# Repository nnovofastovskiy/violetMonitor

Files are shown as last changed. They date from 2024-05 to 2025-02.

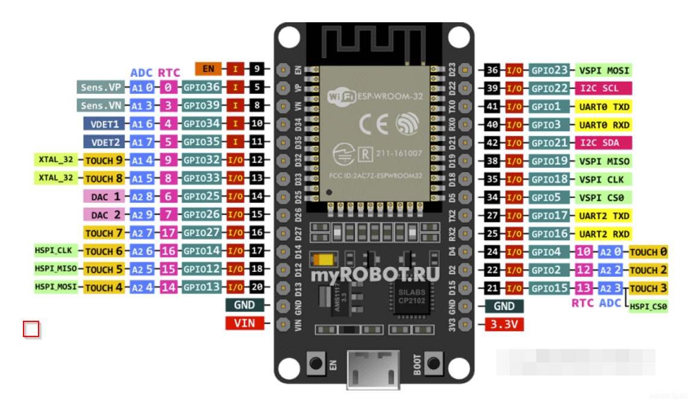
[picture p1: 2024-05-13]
datasheets/esp32_006img03.png





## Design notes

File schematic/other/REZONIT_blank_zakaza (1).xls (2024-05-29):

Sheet: Лист1
8-800-777-80-80 pcb@rezonit.ru
Отправляя заполненный бланк на email: pcb@rezonit.ru я соглашаюсь с условиями Политики обработки персональных данных, даю Согласие на обработку персональных данных (https://www.rezonit.ru/docs/politics/) | https://www.rezonit.ru/docs/politics/ | https://www.rezonit.ru/docs/politics/ | https://www.rezonit.ru/docs/politics/ | https://www.rezonit.ru/docs/politics/ | https://www.rezonit.ru/docs/politics/ | https://www.rezonit.ru/docs/politics/ | https://www.rezonit.ru/docs/politics/ | https://www.rezonit.ru/docs/politics/ | https://www.rezonit.ru/docs/politics/ | https://www.rezonit.ru/docs/politics/ | https://www.rezonit.ru/docs/politics/ | https://www.rezonit.ru/docs/politics/ | https://www.rezonit.ru/docs/politics/ | https://www.rezonit.ru/docs/politics/ | https://www.rezonit.ru/docs/politics/ | https://www.rezonit.ru/docs/politics/ | https://www.rezonit.ru/docs/politics/ | https://www.rezonit.ru/docs/politics/ | https://www.rezonit.ru/docs/politics/ | https://www.rezonit.ru/docs/politics/ | https://www.rezonit.ru/docs/politics/ | https://www.rezonit.ru/docs/politics/
https://www.rezonit.ru/docs/politics/ | https://www.rezonit.ru/docs/politics/ | https://www.rezonit.ru/docs/politics/ | https://www.rezonit.ru/docs/politics/ | https://www.rezonit.ru/docs/politics/ | https://www.rezonit.ru/docs/politics/ | https://www.rezonit.ru/docs/politics/ | https://www.rezonit.ru/docs/politics/ | https://www.rezonit.ru/docs/politics/ | https://www.rezonit.ru/docs/politics/ | https://www.rezonit.ru/docs/politics/ | https://www.rezonit.ru/docs/politics/ | https://www.rezonit.ru/docs/politics/ | https://www.rezonit.ru/docs/politics/ | https://www.rezonit.ru/docs/politics/ | https://www.rezonit.ru/docs/politics/ | https://www.rezonit.ru/docs/politics/ | https://www.rezonit.ru/docs/politics/ | https://www.rezonit.ru/docs/politics/ | https://www.rezonit.ru/docs/politics/ | https://www.rezonit.ru/docs/politics/ | https://www.rezonit.ru/docs/politics/ | https://www.rezonit.ru/docs/politics/
Даю Согласие на получение рассылки рекламно-информационных материалов (https://www.rezonit.ru/docs/soglasie-na-poluchenie-rassylki-reklamno-informatsionnykh-materialov/) | https://www.rezonit.ru/docs/soglasie-na-poluchenie-rassylki-reklamno-informatsionnykh-materialov/ | https://www.rezonit.ru/docs/soglasie-na-poluchenie-rassylki-reklamno-informatsionnykh-materialov/ | https://www.rezonit.ru/docs/soglasie-na-poluchenie-rassylki-reklamno-informatsionnykh-materialov/ | https://www.rezonit.ru/docs/soglasie-na-poluchenie-rassylki-reklamno-informatsionnykh-materialov/ | https://www.rezonit.ru/docs/soglasie-na-poluchenie-rassylki-reklamno-informatsionnykh-materialov/ | https://www.rezonit.ru/docs/soglasie-na-poluchenie-rassylki-reklamno-informatsionnykh-materialov/ | https://www.rezonit.ru/docs/soglasie-na-poluchenie-rassylki-reklamno-informatsionnykh-materialov/ | https://www.rezonit.ru/docs/soglasie-na-poluchenie-rassylki-reklamno-informatsionnykh-materialov/ | https://www.rezonit.ru/docs/soglasie-na-poluchenie-rassylki-reklamno-informatsionnykh-materialov/ | https://www.rezonit.ru/docs/soglasie-na-poluchenie-rassylki-reklamno-informatsionnykh-materialov/ | https://www.rezonit.ru/docs/soglasie-na-poluchenie-rassylki-reklamno-informatsionnykh-materialov/ | https://www.rezonit.ru/docs/soglasie-na-poluchenie-rassylki-reklamno-informatsionnykh-materialov/ | https://www.rezonit.ru/docs/soglasie-na-poluchenie-rassylki-reklamno-informatsionnykh-materialov/ | https://www.rezonit.ru/docs/soglasie-na-poluchenie-rassylki-reklamno-informatsionnykh-materialov/ | https://www.rezonit.ru/docs/soglasie-na-poluchenie-rassylki-reklamno-informatsionnykh-materialov/ | https://www.rezonit.ru/docs/soglasie-na-poluchenie-rassylki-reklamno-informatsionnykh-materialov/ | https://www.rezonit.ru/docs/soglasie-na-poluchenie-rassylki-reklamno-informatsionnykh-materialov/ | https://www.rezonit.ru/docs/soglasie-na-poluchenie-rassylki-reklamno-informatsionnykh-materialov/ | https://www.rezonit.ru/docs/soglasie-na-poluchenie-rassylki-reklamno-informatsionnykh-materialov/ | https://www.rezonit.ru/docs/soglasie-na-poluchenie-rassylki-reklamno-informatsionnykh-materialov/ | https://www.rezonit.ru/docs/soglasie-na-poluchenie-rassylki-reklamno-informatsionnykh-materialov/ | https://www.rezonit.ru/docs/soglasie-na-poluchenie-rassylki-reklamno-informatsionnykh-materialov/
https://www.rezonit.ru/docs/soglasie-na-poluchenie-rassylki-reklamno-informatsionnykh-materialov/ | https://www.rezonit.ru/docs/soglasie-na-poluchenie-rassylki-reklamno-informatsionnykh-materialov/ | https://www.rezonit.ru/docs/soglasie-na-poluchenie-rassylki-reklamno-informatsionnykh-materialov/ | https://www.rezonit.ru/docs/soglasie-na-poluchenie-rassylki-reklamno-informatsionnykh-materialov/ | https://www.rezonit.ru/docs/soglasie-na-poluchenie-rassylki-reklamno-informatsionnykh-materialov/ | https://www.rezonit.ru/docs/soglasie-na-poluchenie-rassylki-reklamno-informatsionnykh-materialov/ | https://www.rezonit.ru/docs/soglasie-na-poluchenie-rassylki-reklamno-informatsionnykh-materialov/ | https://www.rezonit.ru/docs/soglasie-na-poluchenie-rassylki-reklamno-informatsionnykh-materialov/ | https://www.rezonit.ru/docs/soglasie-na-poluchenie-rassylki-reklamno-informatsionnykh-materialov/ | https://www.rezonit.ru/docs/soglasie-na-poluchenie-rassylki-reklamno-informatsionnykh-materialov/ | https://www.rezonit.ru/docs/soglasie-na-poluchenie-rassylki-reklamno-informatsionnykh-materialov/ | https://www.rezonit.ru/docs/soglasie-na-poluchenie-rassylki-reklamno-informatsionnykh-materialov/ | https://www.rezonit.ru/docs/soglasie-na-poluchenie-rassylki-reklamno-informatsionnykh-materialov/ | https://www.rezonit.ru/docs/soglasie-na-poluchenie-rassylki-reklamno-informatsionnykh-materialov/ | https://www.rezonit.ru/docs/soglasie-na-poluchenie-rassylki-reklamno-informatsionnykh-materialov/ | https://www.rezonit.ru/docs/soglasie-na-poluchenie-rassylki-reklamno-informatsionnykh-materialov/ | https://www.rezonit.ru/docs/soglasie-na-poluchenie-rassylki-reklamno-informatsionnykh-materialov/ | https://www.rezonit.ru/docs/soglasie-na-poluchenie-rassylki-reklamno-informatsionnykh-materialov/ | https://www.rezonit.ru/docs/soglasie-na-poluchenie-rassylki-reklamno-informatsionnykh-materialov/ | https://www.rezonit.ru/docs/soglasie-na-poluchenie-rassylki-reklamno-informatsionnykh-materialov/ | https://www.rezonit.ru/docs/soglasie-na-poluchenie-rassylki-reklamno-informatsionnykh-materialov/ | https://www.rezonit.ru/docs/soglasie-na-poluchenie-rassylki-reklamno-informatsionnykh-materialov/ | https://www.rezonit.ru/docs/soglasie-na-poluchenie-rassylki-reklamno-informatsionnykh-materialov/
Наименование компании / ФИО заказчика |  |  |  |  |  |  |  | Новофастовский Никита Андреевич
Вид плательщика |  |  |  |  |  |  |  | Физическое лицо
ФИО плательщика (если различно с заказчиком)
 |  |  |  |  |  |  |  | необходимо заполнить
 |  |  |  |  |  |  |  | необходимо заполнить
Способ получения плат |  |  |  |  |  |  |  | Доставка
Способ доставки |  |  |  |  |  |  |  | Экспресс-доставка
Адрес доставки заказа, примечания по доставке |  |  |  |  |  |  |  | 117342, Россия, г Москва, р-н Коньково, ул Введенского, д 1 стр 21 Адрес проходной предприятия, доставку могу принять с понедельника по пятницу с 10:00 до 18:00, курьеру позвонить за 15 мин до прибытия.
Контактное лицо по доставке (ФИО, email, тел) |  |  |  |  |  |  |  | Новофастовский Никита Андреевич, bananchik26@gmail.com, +7(999)9796726
Контактное лицо по техническим вопросам (ФИО, email, тел) |  |  |  |  |  |  |  | Новофастовский Никита Андреевич, bananchik26@gmail.com, +7(999)9796726
Характеристика проекта |  |  |  |  |  |  |  | ! Убедитесь, что проект платы соответствует нашим технологическим возможностям. В случае несоответствия им адаптация проекта проходит без дополнительного согласования
Наименование файла платы: |  |  |  |  |  |  |  | violetMonitor |  |  |  |  |  |  | Дополнительные требования
Плата изготавливается: впервые / повторно |  |  |  |  |  |  |  | Впервые
Вариант изготовления |  |  |  |  |  |  |  | Суперсрочный
Требуется изготовить, шт |  |  |  |  |  |  |  | 1
Количество проводящих слоев |  |  |  |  |  |  |  | 2
Базовый материал (Core) |  |  |  |  |  |  |  | FR4 Tg135 типовой
Толщина материала (ОПП, ДПП)/Суммарная толщина платы ( МПП), мм |  |  |  |  |  |  |  | 1.500
Толщина фольги, мкм |  |  |  |  |  |  |  | 18
Финишное покрытие площадок |  |  |  |  |  |  |  | ПОС-63
Наличие паяльной маски |  |  |  |  |  |  |  | Маска с 2 сторон |  |  | Зеленого(типового)цвета
Наличие маркировки краской |  |  |  |  |  |  |  | С 2 сторон |  |  | белого(типового)цвета
Монтаж и изготовление трафарета |  |  |  |  |  |  |  | Требуется с закупкой комплектации
Вариант монтажного заказа |  |  |  |  |  |  |  | Срочный
Требуется смонтировать шт |  |  |  |  |  |  |  | 1
Паяльная паста |  |  |  |  |  |  |  | с содержанием свинца (стандартный)
Отмывка плат после монтажа |  |  |  |  |  |  |  | не требуется
Разделение плат после монтажа |  |  |  |  |  |  |  | не требуется
Рентген-контроль |  |  |  |  |  |  |  | не требуется
Перечень технологических слоев |  |  |  |  |  |  |  | поля заполнены типовыми значениями, при необходимости можете заполнить
 |  |  | Имя Gerber файла_Layer name (PCAD200x)_Слои в PCAD4.5(8.5)_DipTrace |  |  |  |  | Типовая сборка |  |  | Требуемая сборка |  | Сверловка, укажите цветом начальный и конечный слой
Контур платы
Маркировка элементов сверху |  |  |  |  |  |  |  |  |  |  |  |  | Сквозные металлизированные отверстия |  | Сквозные неметаллизированные отверстия
Маска верхнего слоя
Верхний слой |  |  |  |  |  |  |  | фольга 18 мкм
Внутренний
Внутренний
Внутренний
Внутренний
 |  |  |  |  |  |  |  | FR4 Tg135 типовой 1,5 мм
Внутренний
Внутренний
Внутренний
Внутренний
Внутренний
Внутренний
Внутренний
Внутренний
Нижний слой |  |  |  |  |  |  |  | фольга 18 мкм
Маска нижнего слоя
Маркировка элементов снизу
PTH
NPTH
Несквозные отверстия 1
Несквозные отверстия 2
Несквозные отверстия 3
Расширенные параметры печатной платы (сборка, мех. обработка и т.д.) |  |  |  |  |  |  |  | поля заполнены типовыми значениями, при необходимости можете изменить их
Электротестирование
Контроль волнового сопротивления (импеданс) |  |  |  |  |  |  |  | Нет
Покрытие краевых разъемов |  |  |  |  |  |  |  | Соответствует финишному покрытию
Фаска 30 грд на краевых разъемах
Механическая обработка контура |  |  |  |  |  |  |  | На усмотрение производства
Металлизированный торец платы |  |  |  |  |  |  |  | Нет
Металлизированные полуотверстия
Металлизированные пазы
Зенковка |  |  |  |  |  |  |  | Нет
Фрезерование на глубину |  |  |  |  |  |  |  | Нет
Структура МПП |  |  |  |  |  |  |  | Типовая
Для PCAD4.5;8.5;2000; Diptrace; Altium Designer переходные |  |  |  |  |  |  |  | Закрыты маской
Тентирование переходных отверстий |  |  |  |  |  |  |  | Не требуется
Для экспорта шелкографии в PCAD200x мы используем след. настройки по умолчанию |  |  |  |  |  |  |  | RefDes | On | Type | Off | Value | Off
Панелизация |  |  |  |  |  |  |  | На усмотрение производcтва |  |  |  |  |  |  | Панелизация необходима для качественного монтажа электронных компонентов. Если платы будут монтироваться в компании Резонит рекомендуем выбрать раскладку панели «На усмотрение производcтва». ! Монтаж единичных плат, не объединенных в заготовку, невозможен на нашем производстве.
Длина платы (по горизонтали), мм
Ширина платы (по вертикали), мм
Количество плат по горизонтали
Количество плат по вертикали
Зазор между платами по горизонтали
Зазор между платами по вертикали
Ширина полей по горизонтали
Ширина полей по вертикали
Маркировка плат по ГОСТ 30668-2000
Ремонт на печатных платах по ГОСТ Р 55491-2013 |  |  |  |  |  |  |  | Допускается
Нулевой дефект на панели (No X-out) |  |  |  |  |  |  |  | Нет
Описание PIN & VIA PCAD-4.5 и PCAD8.5.
Масштаб изготовления фотошаблона |  |  |  |  |  |  |  | 1:1
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

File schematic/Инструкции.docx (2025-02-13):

При включении контроллер проверяет наличие сохраненных данных wifi и url, при отсутствии данных запускается точка доступа с названием “violetMonitor”. При подключении к этой точке доступа автоматически откроется веб-страница для настройки (по адресу 192.168.4.1, таймаут для подключения к точке доступа 20 секунд; если не подключиться к точке доступа питание отключится, включить его можно кнопкой включения).

На странице настроек нужно сначала перейти на страницу «Параметры», ввести URL для получения данных, изменить если нужно частоту обновления данных и яркость светодиода и нажать «Сохранить», после этого, вернуться на главную страницу.

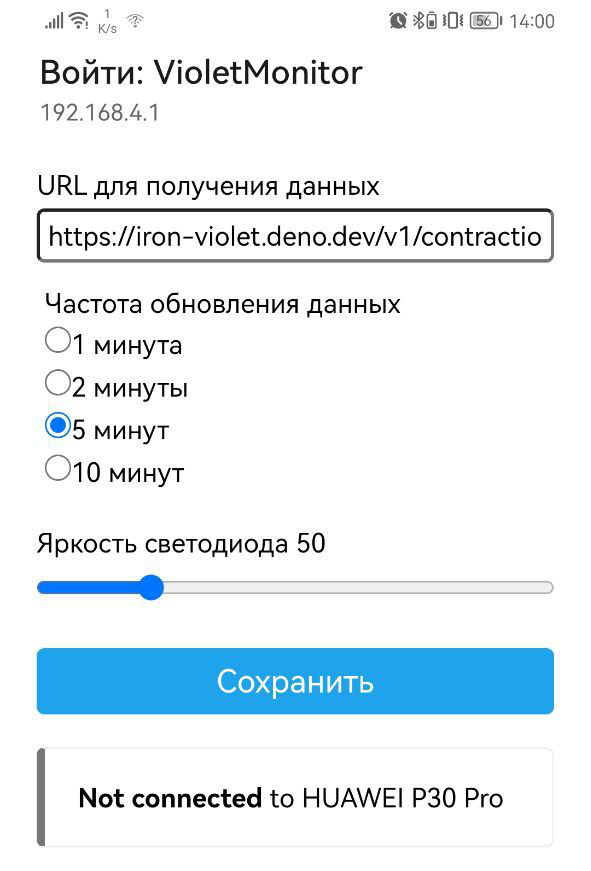
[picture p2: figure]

Далее нажать «Настроить WiFi».

На странице настройки WiFi выбрать сеть из списка, ввести пароль этой сети и нажать «Сохранить», после этого точка доступа отключится, и устройство попытается подключиться к сохраненной WiFi сети.

Если подключиться не получится, автоматически запустится точка доступа и можно будет исправить настройки.

Если подключение к wifi произошло, контроллер выполнит http запрос по сохраненному url, получит данные, распарсит их и начнет измерение уровня заряда аккумулятора (кол-во импульсов с микросхемы контроллера питания).

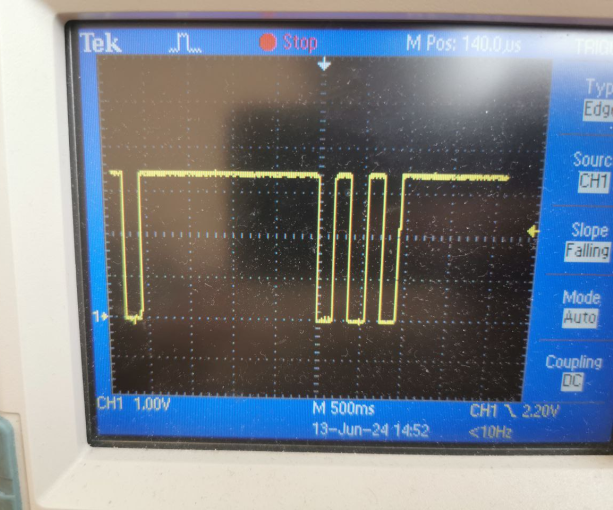
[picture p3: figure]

После измерения информация выводится на дисплей, и контроллер переходит в режим глубокого сна на заданное время.

После пробуждения алгоритм повторяется.

Устройство можно выключить/включить кнопкой вкл/выкл.

Точку доступа можно принудительно запустить соответствующей кнопкой для изменения настроек.

Во время зарядки отображается значок .

Когда аккумулятор полностью зарядится, отобразится значок .

Когда аккумулятор полностью разрядится, информация на дисплее останется в последнем состоянии, но светодиод погаснет.

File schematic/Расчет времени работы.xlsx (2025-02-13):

частота мин | ток | секунды | потребление мА/ч | емкость мАч | часов | дней
1 | 120 | 4 | 20.85 | 2000 | 95.92326139 | 3.996802558
 | 70 | 9
 | 3 | 47

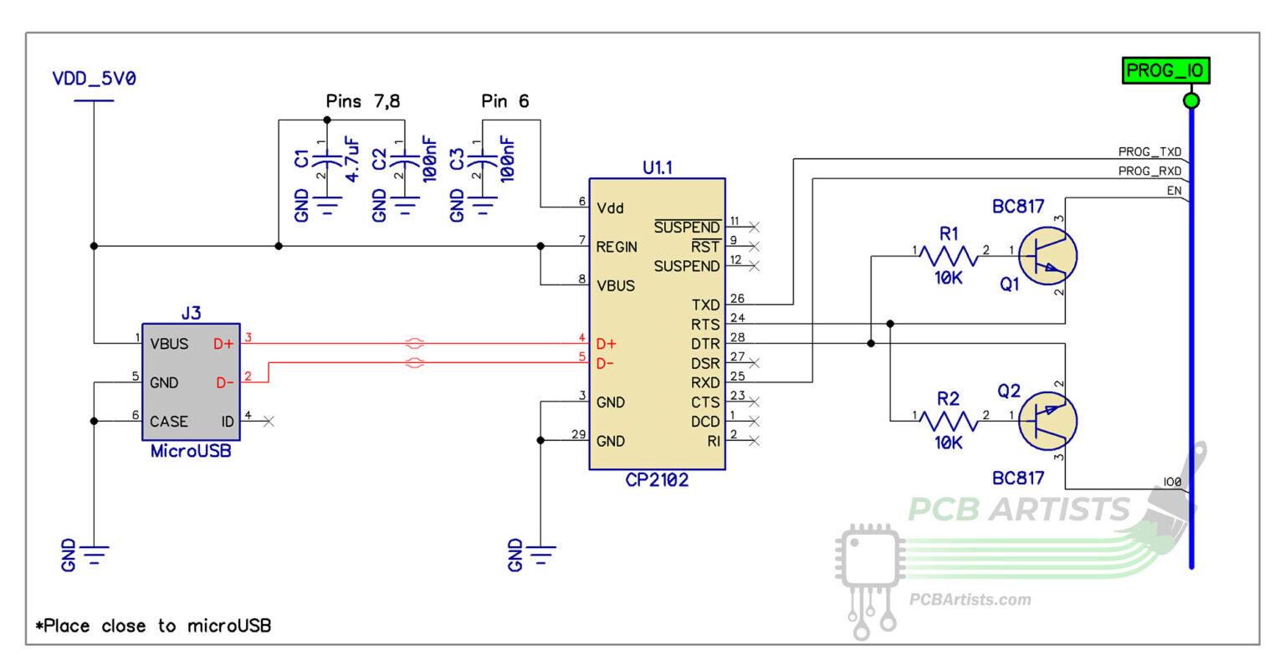
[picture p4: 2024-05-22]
datasheets/esp32-cp2102-programmer-schematic-for-espressif-esp32-esp8266-1536x802.jpg

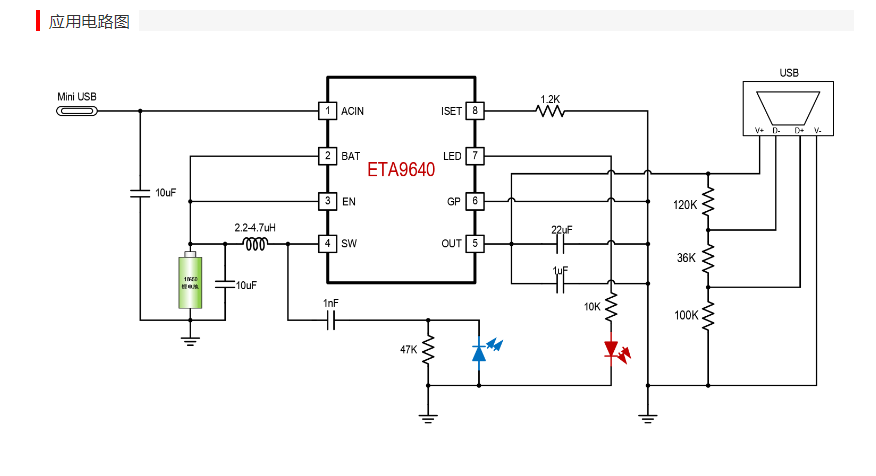
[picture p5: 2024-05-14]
datasheets/eta9640.png

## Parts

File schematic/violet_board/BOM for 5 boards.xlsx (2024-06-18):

# | RefDes | Name | Pattern | Value | Quantity | Всего нужно | На руках | Купить
1 | C1, C2, C7 | GRM21BR61A106KE19B | CAP_0805_L | 10uF | 3 | 15 | 4 | 11
2 | C3 | GRM32ER71E226KE15L | CAP_1210_L | 22uF | 1 | 5 | 8 | 0
3 | C4, C9, C10, C11 | GRM155R61C105KA12D | CAP_0402_L | 1uF | 4 | 20 | 0 | 20
4 | C5 | GRM2165C1H471JA01D | CAP_0805_L | 470pF | 1 | 5 | 8 | 0
5 | C6 | TECAP2.2/16VA10 | CAPPM320X160X185L80X120N | 2.2uF | 1 | 5 | 0 | 5
6 | C8, C12 | GRM21BR71H104K | CAP_0805_L | 0.1uF | 2 | 10 | 9 | 1
7 | IC1 | SK6805-2427 | SK68052427 |  | 1 | 5 | 8 | 0
8 | L1 | B82472G6472M000 | IND(4.7)_B82472G6472M000 | 4.7uH | 1 | 5 | 2 | 3
9 | Q1, Q2 | BSS138LT1G | SOT23-3P95_240X110L43X44N |  | 2 | 10 | 9 | 1
10 | Q3, Q4 | BC817-16,235 | SOT23-3P95_230X110L30X43N |  | 2 | 10 | 10 | 0
11 | R1 | RC0402FR-071K2L | RES_0402_L | 1.2k | 1 | 5 | 18 | 0
12 | R2, R3, R4, R8 | RC0402FR-0730KL | RES_0402_L | 30k | 4 | 20 | 15 | 5
13 | R5, R9, R10, R11, R12 | RC0805JR-0710KL | RES_0805_L | 10k | 5 | 25 | 10 | 15
14 | R6, R7 | RC0402JR-07390RL | RES_0402_L | 390R | 2 | 10 | 16 | 0
15 | U1 | ETA9640 | SOIC9P127_493X599X154L63X40T285X225M |  | 1 | 5 | 10 | 0
16 | U2 | MIC5219-3.3YM5 | SOT23-5 |  | 1 | 5 | 9 | 0
17 | U3 | ESP32-WROOM-32 | MODULE_ESP32-WROOM-32 |  | 1 | 5 | 0 | 5
18 | XP1, XP2, XP5, XP6, XP7 | DS1066-02M | DS1066-02M |  | 5 | 25 | 10 | 15
19 | XP3, XP4 | PLS_20 | PLS_20 |  | 2 | 10 | 4 | 6
20 | XP8 | PLS_6R | PLS_6R |  | 1 | 5 | 4 | 1
21 |  | DS1066-02F |  |  | 5 | 25 | 5 | 20
22 |  | LP103450-PCM |  |  | 1 | 5 | 0 | 5
23 |  | Pico-ePaper-2.9 | 9000791762 |  | 1 | 5 | 0 | 5

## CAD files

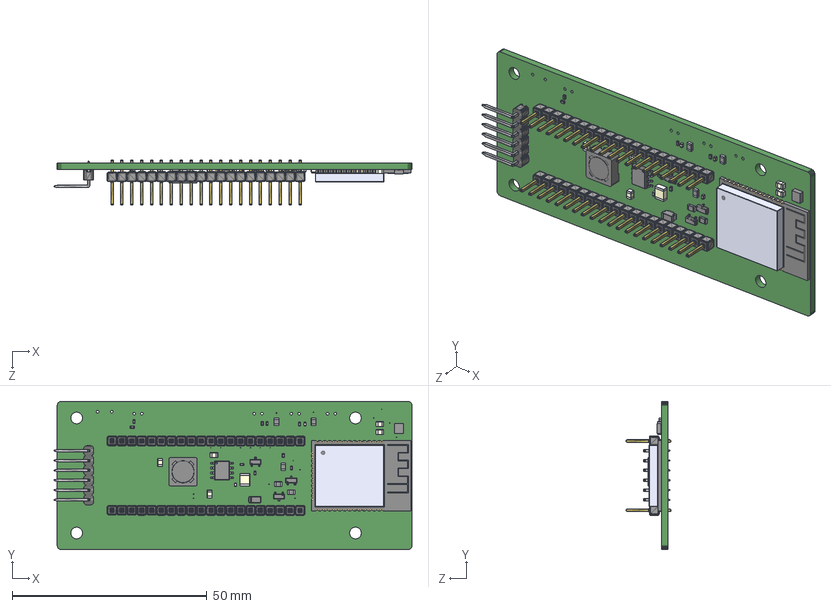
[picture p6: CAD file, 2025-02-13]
schematic/other/main.step
91.8 x 38.0 x 11.6 mm
Board___wctmp
GRM21BR61A106KE19B x 5
GRM32ER71E226KE15L
GRM155R61C105KA12D x 4
TECAP2.2/16VA10
t_mod_0 x 2
BSS138LT1G
BC817-16,235 x 2
RC0402FR-071K2L x 7
RC0805JR-0710KL x 5
ETA9640
t_mod_1
pls_20 x 2
pls_6R

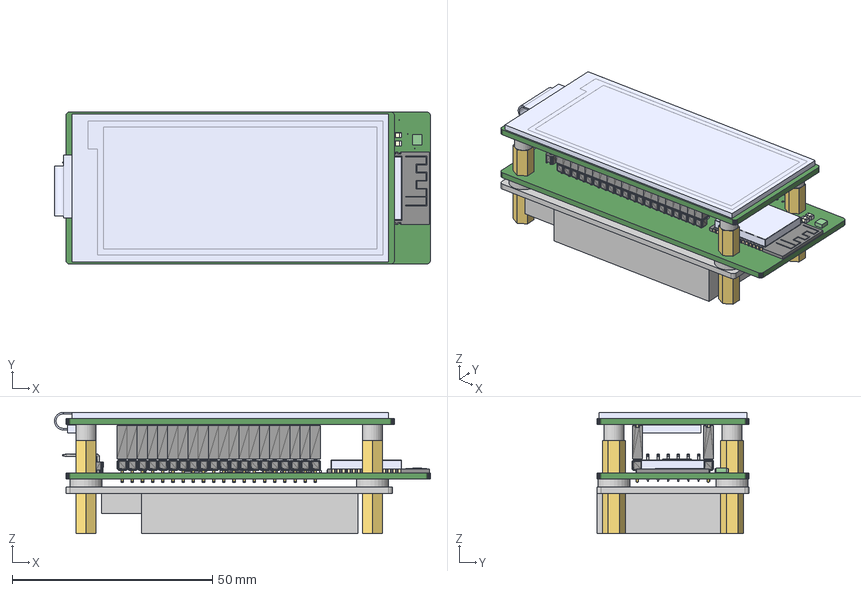
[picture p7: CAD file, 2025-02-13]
schematic/other/Assembly v9.step
93.8 x 38.0 x 30.3 mm
PCHSN-8 x 4
Board___wctmp
GRM21BR61A106KE19B x 5
GRM32ER71E226KE15L
GRM155R61C105KA12D x 4
TECAP2.2/16VA10
t_mod_0
t_mod_0 (1)
BSS138LT1G
BC817-16,235 x 2
RC0402FR-071K2L x 7
RC0805JR-0710KL x 5
ETA9640
t_mod_1
pls_20 x 2
pls_6R
Board___wctmp_1
PBS_20 x 2
LP103450 battery
Plane
PCHSN-10 v1 x 4

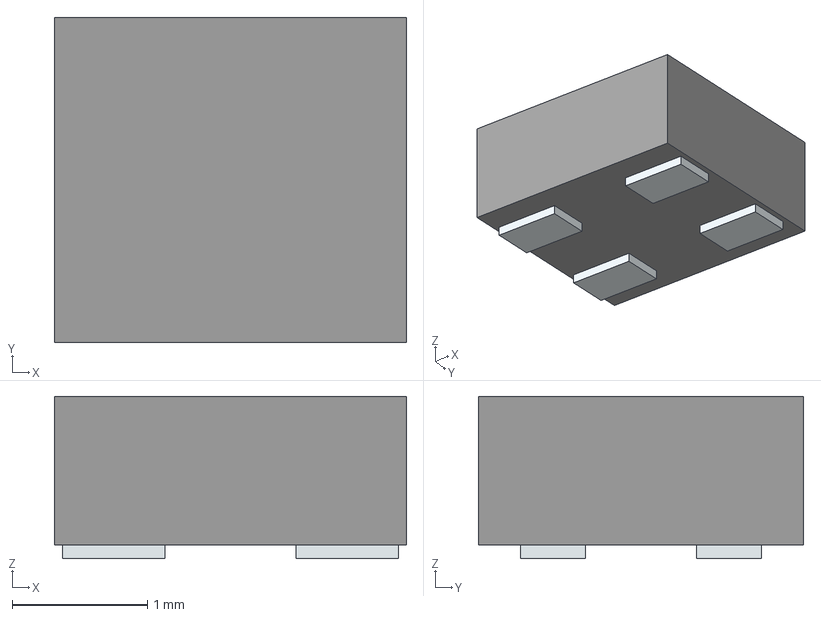
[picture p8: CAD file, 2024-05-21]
schematic/My Libraries/SK6805-2427.stp
2.60 x 2.40 x 1.20 mm
Pins

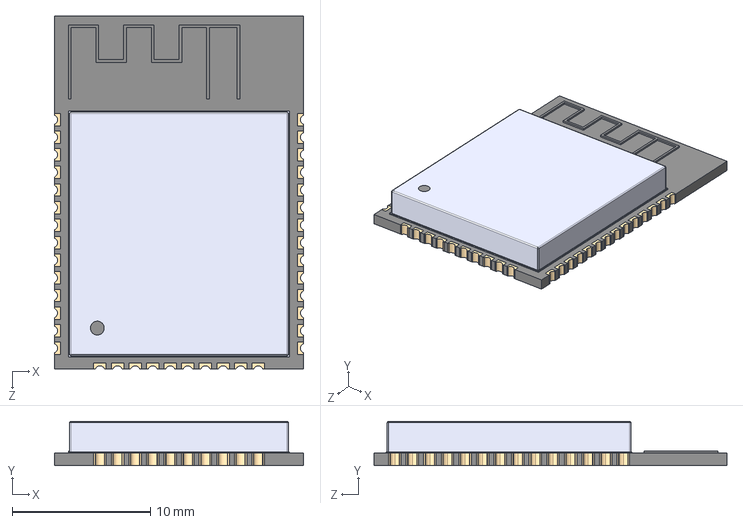
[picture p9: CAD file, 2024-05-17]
schematic/My Libraries/ESP32-WROOM-32--3DModel-STEP-1.STEP
18.0 x 3.20 x 25.5 mm

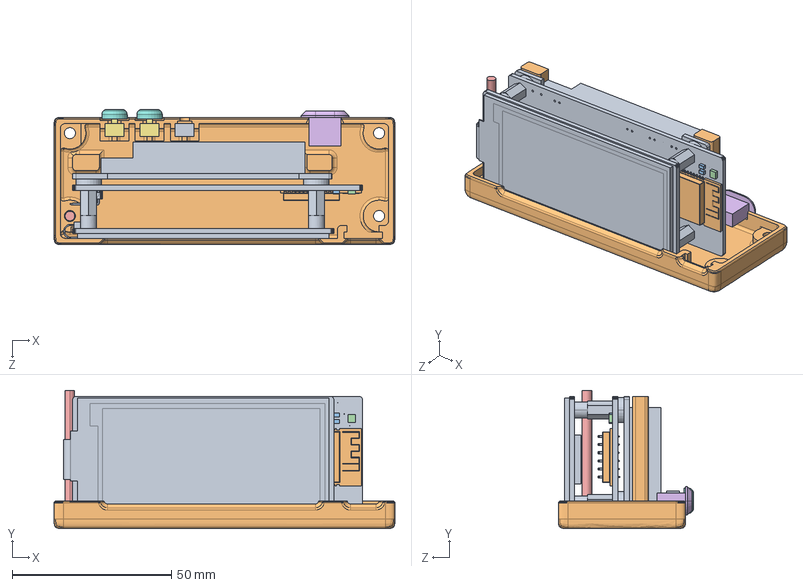
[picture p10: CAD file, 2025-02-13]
schematic/other/sketch_0.2.STEP
107.1 x 43.4 x 42.5 mm

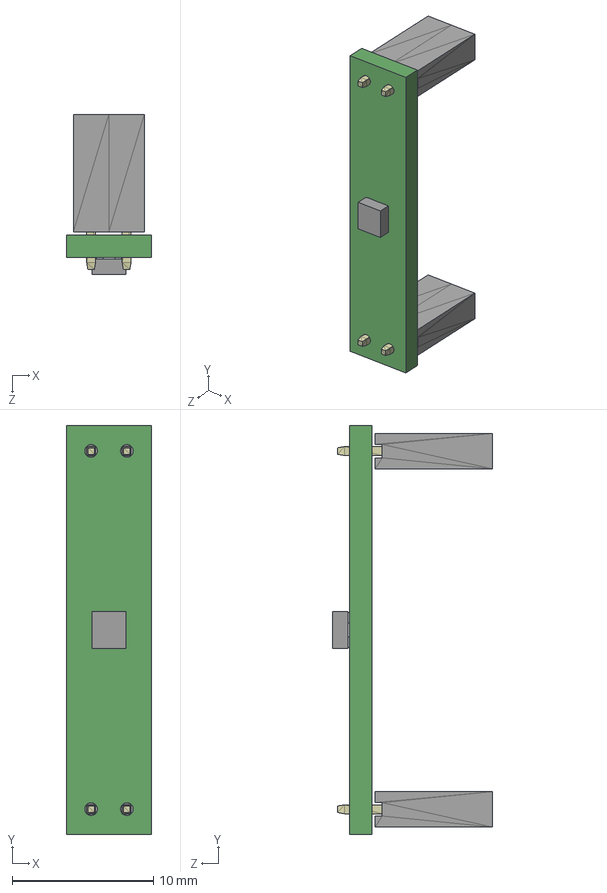
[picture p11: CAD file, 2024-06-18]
schematic/other/led_board.step
6.00 x 29.0 x 11.4 mm
Board_led_board
SK6805-2427
PBS_2 x 2

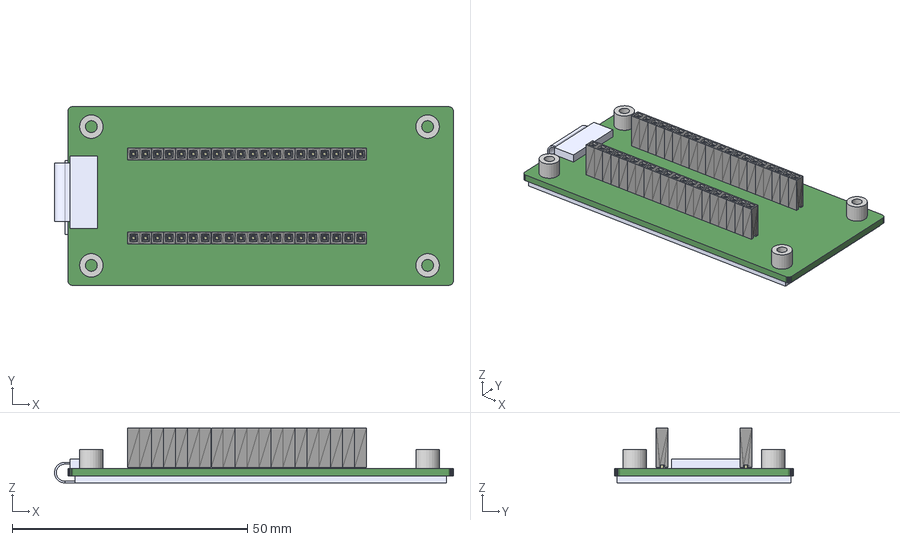
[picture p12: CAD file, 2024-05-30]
schematic/other/display v8.step
84.8 x 38.0 x 11.7 mm
Board___wctmp
PBS_20 x 2

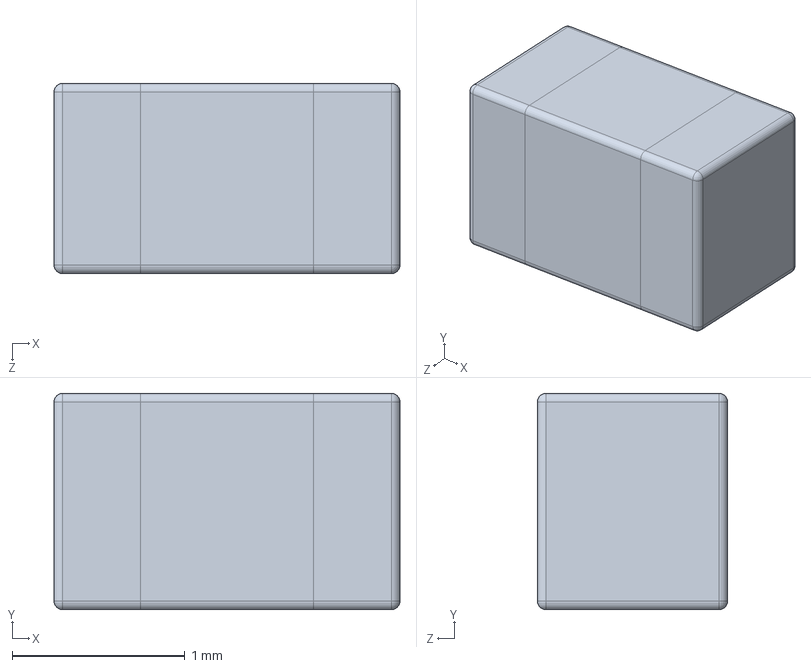
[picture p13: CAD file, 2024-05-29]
schematic/other/GRM21BR61A106KE19B.step.SLDPRT
2.00 x 1.25 x 1.10 mm

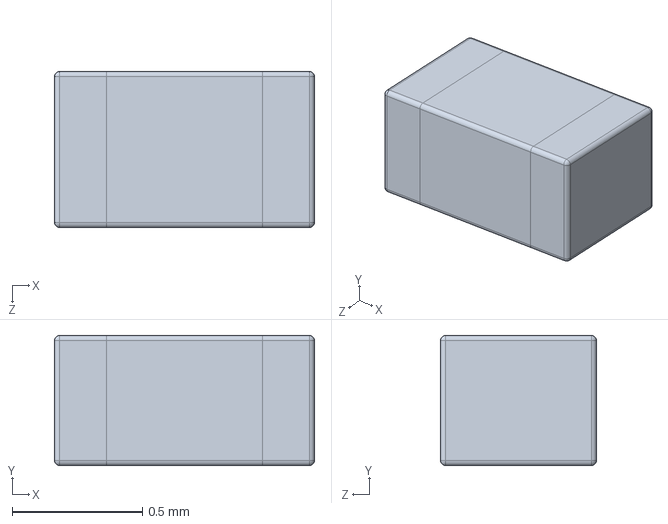
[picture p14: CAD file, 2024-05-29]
schematic/other/GRM155R61C105KA12D.step.SLDPRT
1.00 x 0.5 x 0.6 mm

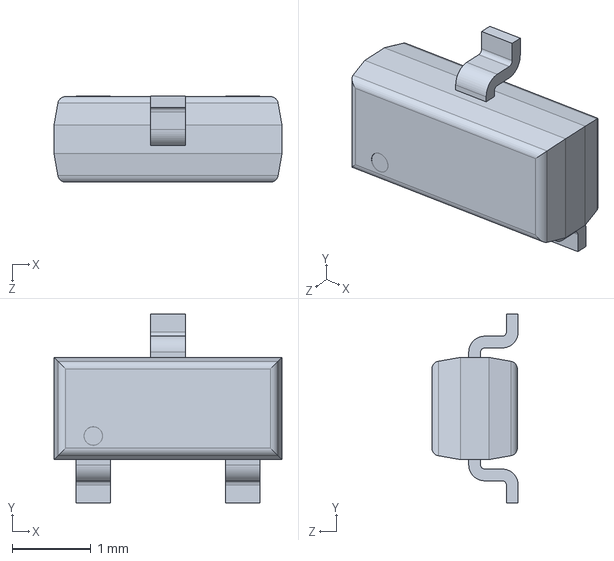
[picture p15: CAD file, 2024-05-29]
schematic/other/BSS138LT1G.step.SLDPRT
2.90 x 2.40 x 1.10 mm

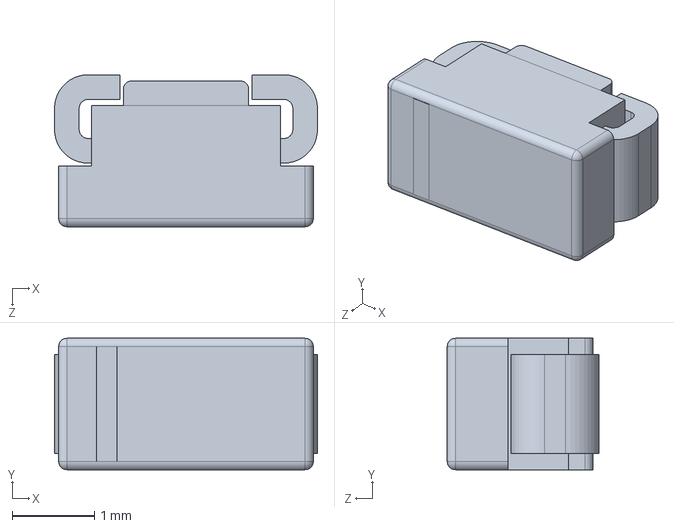
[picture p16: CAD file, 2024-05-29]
schematic/other/TECAP2.2_16VA10.step.SLDPRT
3.20 x 1.60 x 1.86 mm

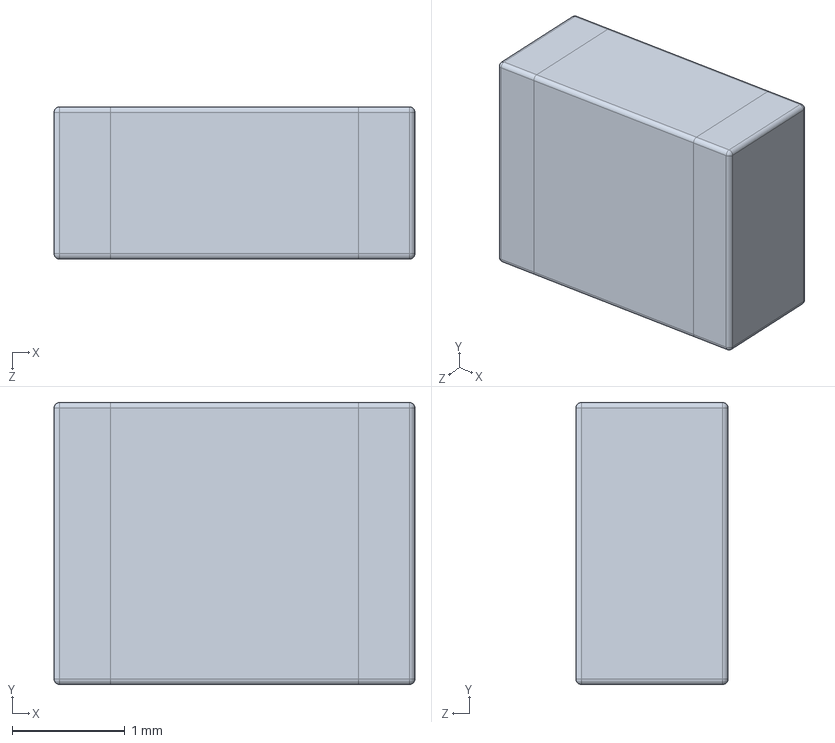
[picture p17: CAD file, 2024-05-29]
schematic/other/GRM32ER71E226KE15L.step.SLDPRT
3.20 x 2.50 x 1.35 mm

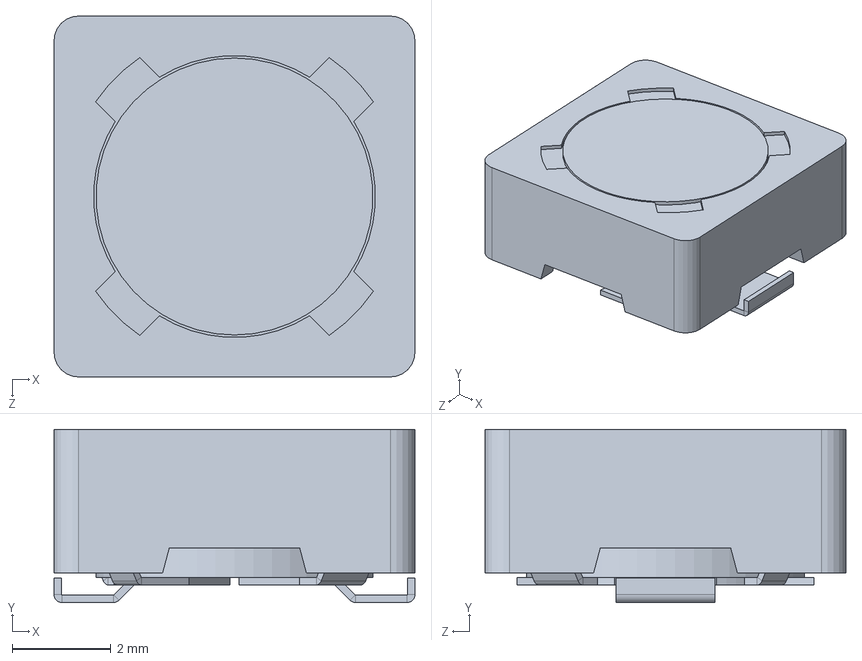
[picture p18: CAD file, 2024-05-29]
schematic/other/t_mod_0 (1).step.SLDPRT
7.30 x 3.50 x 7.30 mm

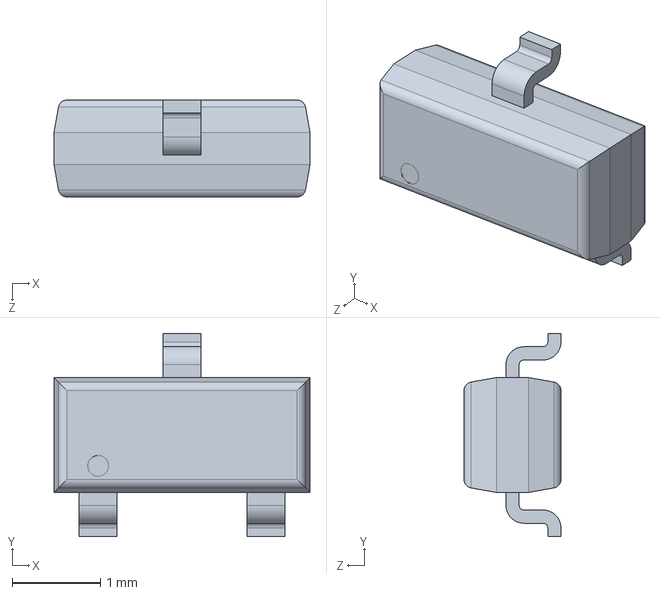
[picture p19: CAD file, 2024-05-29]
schematic/other/BC817-16,235.step.SLDPRT
2.90 x 2.30 x 1.10 mm

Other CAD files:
schematic/other/t_mod_0.step.SLDPRT
schematic/other/display.wrl.SLDPRT
schematic/My Libraries/B82472G6472M000.STEP
schematic/other/Assembly v8.step
schematic/other/display.dwg
schematic/other/display.step

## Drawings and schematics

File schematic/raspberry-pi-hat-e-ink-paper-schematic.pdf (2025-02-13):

VCOM 24 | PREVGL 23 | VSL 22 | PREVGH 21 | VSH 20 | VPP 19 | VDD 18 | VSS 17 | VCI 16 | VDDIO 15 | SDI 14 | SCLK 13 | CS 12 | D/C 11 | RST 10 | BUSY 9 | BS 8 | TSDA 7 | TSCL 6 | VGH 5 | VGL 4 | RESE 3 | GDR 2 | HLT_CTL 1

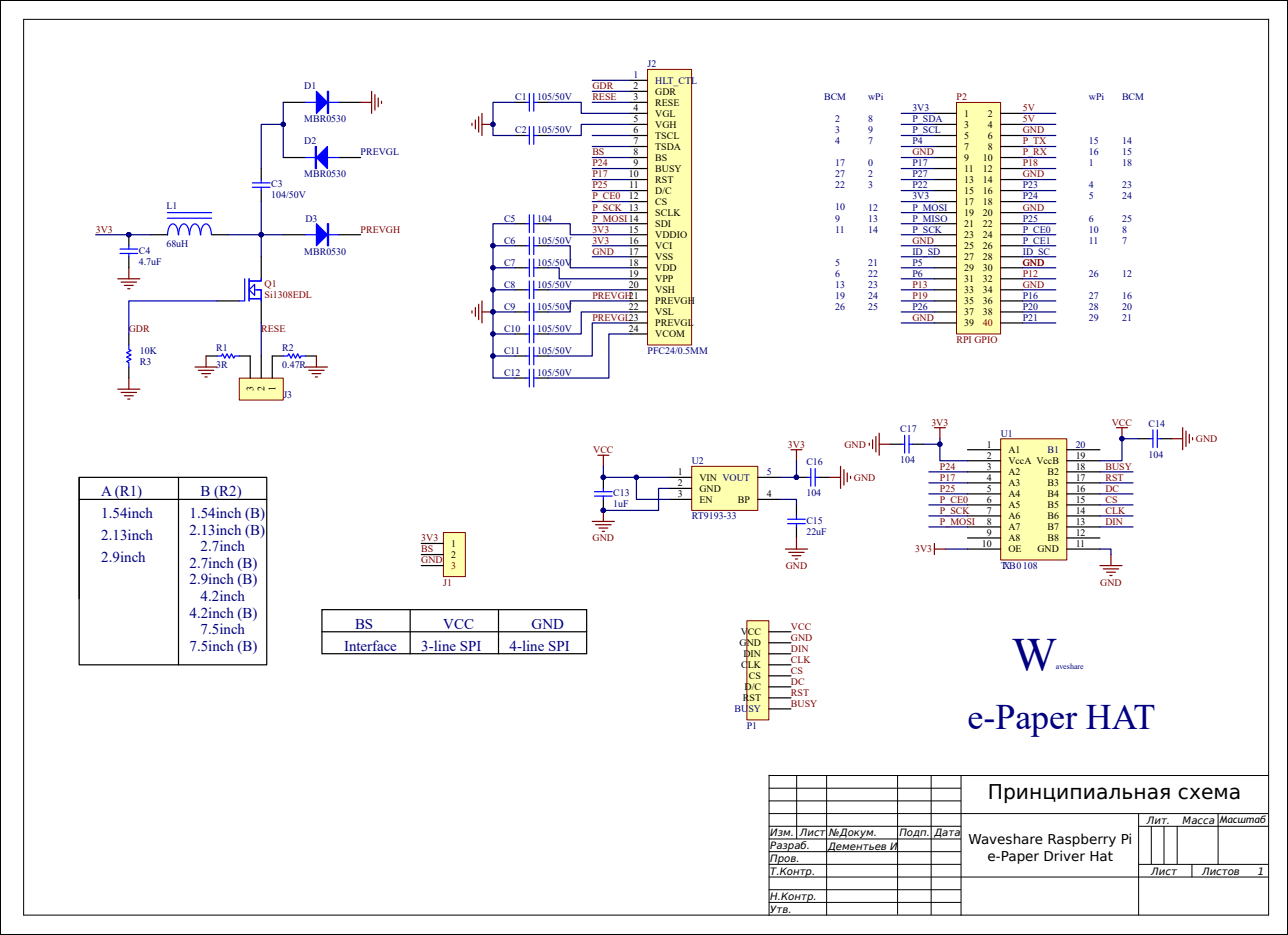
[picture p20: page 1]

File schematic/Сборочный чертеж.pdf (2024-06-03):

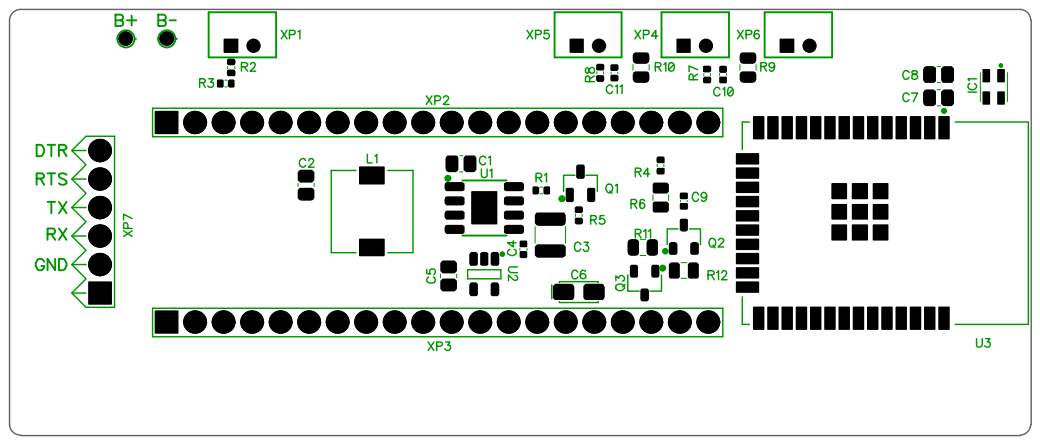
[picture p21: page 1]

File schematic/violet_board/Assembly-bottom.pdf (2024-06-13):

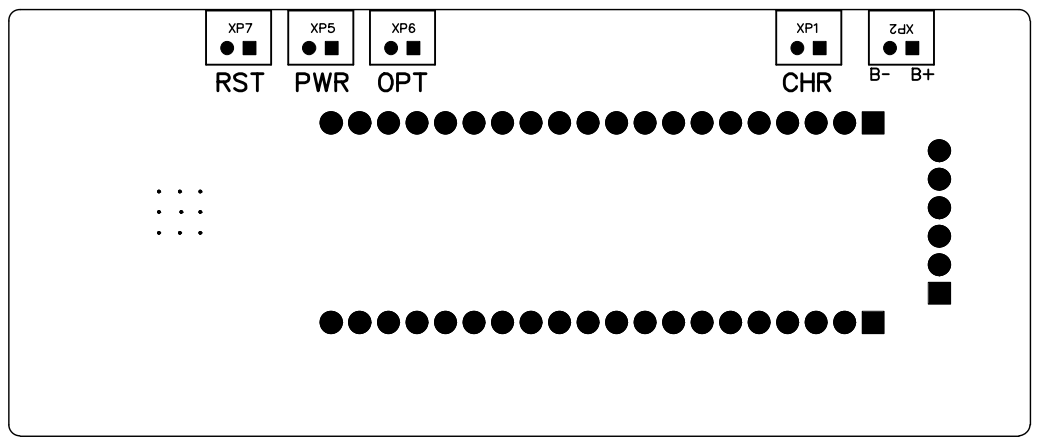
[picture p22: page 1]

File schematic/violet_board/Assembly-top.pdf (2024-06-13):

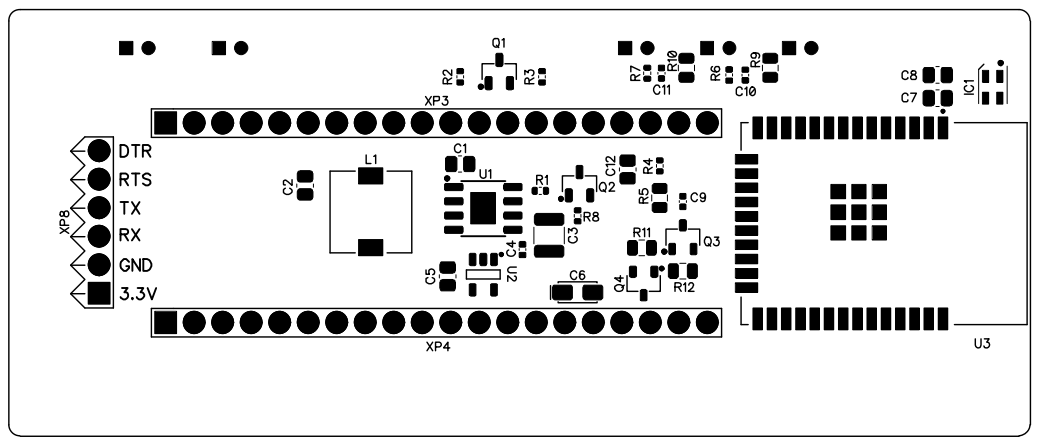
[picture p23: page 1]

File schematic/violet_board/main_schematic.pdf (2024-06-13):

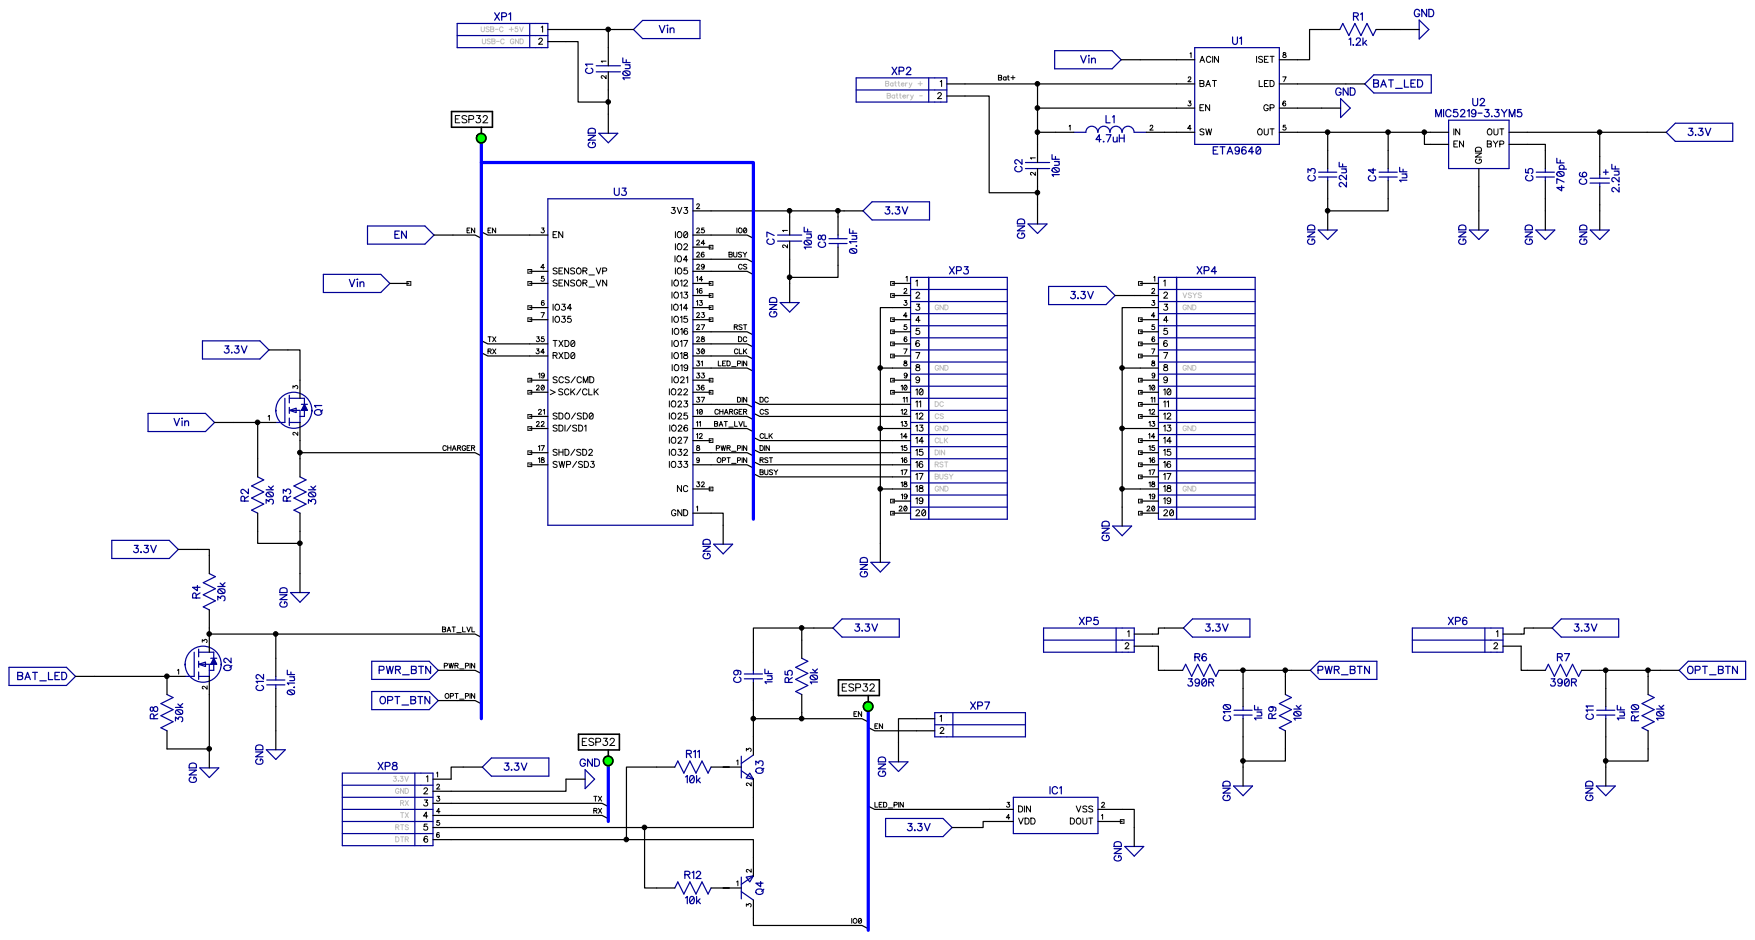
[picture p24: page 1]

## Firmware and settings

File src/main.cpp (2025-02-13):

/**
 * WiFiManager advanced demo, contains advanced configurartion options
 * Implements TRIGGEN_PIN button press, press for ondemand configportal, hold for 3 seconds for reset settings.
 */

// Собственное потребление схемы ~1.4мА (при выключенном светодиоде)
// Потребление при яркости 255 (100%) 9.3мА
// Оптимальное потребление при яркости 55 3мА

// #include <FS.h>
#include <Arduino.h>
#include <main.h>
#include <display.h>
#include <GxEPD.h>

// #include <SPIFFS.h>
#include <ArduinoJson.h> //https://github.com/bblanchon/ArduinoJson
#include <Preferences.h>
// #include <display.h>
// #include <GxEPD2.h>
// #include <GxEPD2_BW.h>
// #include <GxEPD2_display_selection_new_style.h>
// #include <FontsRus/FreeMonoBold18.h>
// #include <FontsRus/FreeSerif10.h>
// #include <FontsRus/TimesNRCyr10.h>
#include <WiFiManager.h> // https://github.com/tzapu/WiFiManager
#include <HTTPClient.h>
#include <FontsRus/MSSansSerif14.h>
#include <FontsRus/MSSansSerif18.h>
#include <FontsRus/MSSansSerif30.h>
#include <FontsRus/JetBrainsMonoThin14.h>
#include <FontsRus/JetBrainsMonoThin30.h>
#include <FontsRus/JetBrainsMono12.h>
#include <FontsRus/JetBrainsMono14.h>
#include <FontsRus/JetBrainsMono15.h>
#include <FontsRus/JetBrainsMono30.h>
#include <FontsRus/BatFont.h>

// #define GxEPD2_DRIVER_CLASS GxEPD2_290_T94_V2
#include <Adafruit_NeoPixel.h>

// #define STANDALONE

#include <GxDEPG0290BS/GxDEPG0290BS.h> // 2.9" b/w Waveshare variant, TTGO T5 V2.4.1 2.9"

#include <GxIO/GxIO_SPI/GxIO_SPI.h>
#include <GxIO/GxIO.h>

// #define TRIGGER_PIN 0
#define BIG_FONT &MSSansSerif30
#define NORM_FONT &MSSansSerif18
#define MIN_FONT &MSSansSerif14

// #define updateTime 600e6 // us

#define OPTIONS_PIN GPIO_NUM_33
#define POWER_PIN GPIO_NUM_32

// #define ASIDE_WIDTH 90
// #define DISPLAY_PADDING 4

#define LED_PIN GPIO_NUM_19
// #define BRIGHTNESS 40 // 0 - 255

#define CHARGER_PIN GPIO_NUM_25
#define BAT_LEVEL_PIN GPIO_NUM_26

#define WAKEUP_PINS_BITMAP 0x302000000
// long WAKEUP_PINS_BITMAP = 1 << OPTIONS_PIN | 1 << POWER_PIN | 1 << CHARGER_PIN;
bool shouldSaveConfig = false;

// wifimanager can run in a blocking mode or a non blocking mode
// Be sure to know how to process loops with no delay() if using non blocking
bool wm_nonblocking = false; // change to true to use non blocking

WiFiManager wm;                    // global wm instance
WiFiManagerParameter custom_field; // global param ( for non blocking w params )
HTTPClient http;

Preferences preferences;

String url;
String update_time = "2";
String brightness = "40";
// String getHooksUrl = "https://iron-violet.deno.dev/v1/available-webhooks";

// Allocate the JSON document
JsonDocument doc;

RTC_DATA_ATTR volatile bool optionsBtnPressed = false;
RTC_DATA_ATTR volatile bool turnOffFlag = false;
RTC_DATA_ATTR int chargerOn = 0;

long sleepTimeMs[4] = {60000, 120000, 300000, 600000};

// int startTime = 0;
int batLevel = 0;
// int levelFronts = 0;
// int betweenFronts = 0;
// int prevMillis = 0;
bool levelReady = false;
bool levelDone = false;

bool chargeDone = false;
bool prevBatLevel;
char *batLevelStr[6] = {"0", "1", "2", "3", "4", "5"};

// unsigned long start_time;
// RTC_DATA_ATTR volatile bool powerBtnPushed = false;

// BUSY -> 4, RST -> 16, DC -> 17, CS -> SS(5), CLK -> SCK(18), DIN -> MOSI(23), GND -> GND, 3.3V -> 3.3V
GxIO_Class io(SPI, /*CS=5*/ SS, /*DC=*/17, /*RST=*/16); // arbitrary selection of 17, 16
GxEPD_Class display(io, /*RST=*/16, /*BUSY=*/4);        // arbitrary selection of (16), 4

Adafruit_NeoPixel pixels(1, LED_PIN, NEO_GRB + NEO_KHZ800);

void IRAM_ATTR optionsIsr()
{
  http.end();
  optionsBtnPressed = !optionsBtnPressed;
  esp_sleep_enable_timer_wakeup(1);
  esp_deep_sleep_start();
}

void IRAM_ATTR powerIsr()
{
  Serial.print("POWER_PIN = ");
  Serial.println(digitalRead(POWER_PIN));
  if (digitalRead(POWER_PIN))
  {
    // Serial.print("========powerBtnPushed = ");
    // Serial.println(powerBtnPushed);
    turnOffFlag = true;
    esp_sleep_enable_timer_wakeup(1);
    esp_deep_sleep_start();
  }
}

void IRAM_ATTR chargerIsr()
{
  if (digitalRead(CHARGER_PIN))
  {
    chargerOn = 1;
    esp_sleep_enable_timer_wakeup(1);
    esp_deep_sleep_start();
  }
  else
  {
    chargerOn = 0;
    esp_sleep_enable_timer_wakeup(1);
    esp_deep_sleep_start();
  }
}

void saveWifiCallback()
{
  Serial.println("[CALLBACK] saveCallback fired");
}

void timeoutCallback()
{
  Serial.println("TURNING OFF BY timeout");
  turningOff();
  // pixels.clear();
  // pixels.show();
  // String text = "Выключено";
  // drawStatusText(&display, strToChar(utf8rus(text)), &MSSansSerif14);
  // esp_sleep_enable_ext1_wakeup(0x100000000, ESP_EXT1_WAKEUP_ANY_HIGH); // 1 = High, 0 = Low
  // esp_deep_sleep_start();
}

void handleExit()
{
  Serial.println("========= Web portal CLOSE");
  wm.handleExit();
  wm.stopWebPortal();
  esp_restart();
}

void configModeCallback(WiFiManager *myWiFiManager)
{
  pixels.clear();
  pixels.show();
  String text = "Точка доступа";
  drawStatusText(&display, strToChar(utf8rus(text)), NORM_FONT);
  Serial.println("[CALLBACK] configModeCallback fired");
  // myWiFiManager->setAPStaticIPConfig(IPAddress(10,0,1,1), IPAddress(10,0,1,1), IPAddress(255,255,255,0));
  // Serial.println(WiFi.softAPIP());
  // if you used auto generated SSID, print it
  // Serial.println(myWiFiManager->getConfigPortalSSID());
  //
  // esp_wifi_set_bandwidth(WIFI_IF_AP, WIFI_BW_HT20);
}

// void saveParamCallback()
// {
//   Serial.println("[CALLBACK] saveParamCallback fired");
//   // wm.stopConfigPortal();
// }

void bindServerCallback()
{
  // wm.server->on("/custom",handleRoute);

  // you can override wm route endpoints, I have not found a way to remove handlers, but this would let you disable them or add auth etc.
  // wm.server->on("/info",handleNotFound);
  // wm.server->on("/update",handleNotFound);
  // wm.server->on("/erase",handleNotFound); // disable erase
  wm.server->on("/exit", handleExit);
}

void setup()
{
  // start_time = millis();
  Serial.begin(115200);
  Serial.println("_____START_____");
#ifndef STANDALONE
  check_wakeup_reason();
  delay(100);
  Serial.print(" +++++++++++++++++ turnOffFlag = ");
  Serial.println(turnOffFlag);
  if (turnOffFlag)
  {
    Serial.println("TURNING OFF BY powerBtnPressed");
    turningOff();
  }
  pinMode(CHARGER_PIN, INPUT);
  pinMode(BAT_LEVEL_PIN, INPUT);
  attachInterrupt(digitalPinToInterrupt(POWER_PIN), powerIsr, RISING);
  attachInterrupt(digitalPinToInterrupt(OPTIONS_PIN), optionsIsr, RISING);
  // Serial.print("+++++++++++++ analogRead(CHARGER) = ");
  // Serial.println(analogRead(CHARGER_PIN));
  attachInterrupt(digitalPinToInterrupt(CHARGER_PIN), chargerIsr, CHANGE);
#endif
  // if (chargerOn)
  // {
  //   display.init(115200);
  //   display.flush();
  //   drawBat(&display, batLevelStr[5], &BatFont, true);
  //   display.powerDown();
  // }
  // drawBat(&display, batLevelStr[5], &BatFont, false);
  // attachInterrupt(digitalPinToInterrupt(BAT_LEVEL_PIN), batLeverIsr, CHANGE);

  // while (!levelDone)
  // {
  //   delay(1);
  // }
  // Serial.print("========= batLevel = ");
  // Serial.println(batLevel);

  pixels.begin(); // INITIALIZE NeoPixel strip object (REQUIRED)

  // esp_sleep_enable_ext0_wakeup(OPTIONS_PIN, 1); // 1 = High, 0 = Low
  chargerOn = digitalRead(CHARGER_PIN);
  Serial.print("+++++++++++++++++++ chargerOn = ");
  // Serial.print(digitalRead(CHARGER_PIN));
  Serial.print("   ");
  Serial.println(chargerOn);
  // delay(3000);
  // attachInterrupt(POWER_PIN, powerIsrOff, FALLING);
  // while(powerBtnPushed);

  esp_sleep_enable_ext1_wakeup(WAKEUP_PINS_BITMAP, ESP_EXT1_WAKEUP_ANY_HIGH); // 1 = High, 0 = Low
  Serial.println("\n Starting");

  preferences.begin("preferences", false);
  url = preferences.getString("url");
  update_time = preferences.getString("update_time");
  brightness = preferences.getString("brightness");
  preferences.end();
  Serial.println("URL = " + url);
  Serial.println("update_time = " + update_time);
  uint8_t bri = brightness.toInt();
  Serial.print("brightness = ");
  Serial.println(bri);
  Serial.println("====================== sleep time = ");

  // Serial.println(sleepTimeMs[update_time.toInt()] * 1000);
  // esp_sleep_enable_timer_wakeup(sleepTimeMs[update_time.toInt()] * 1000);

  // switch (update_time)
  // {
  // case '0':
  //   sleepTimeMs = 60e3;
  //   break;
  // case '1':
  //   sleepTimeMs = 60e3 * 5;
  //   break;
  // case '2':
  //   sleepTimeMs = 60e3 * 10;
  //   break;

  // default:
  //   break;
  // }
  uint8_t ut = update_time.toInt();
  Serial.println("update_time = " + ut);

  configWM();

  if (url == "" || optionsBtnPressed)
  {
    // String text = "Точка доступа";
    if (url == "")
    {
      String text = "URL пуст";
      drawStatusText(&display, strToChar(utf8rus(text)), NORM_FONT);
    }

    // if (optionsBtnPressed)
    optionsBtnPressed = false;
    if (!wm.startConfigPortal("VioletMonitor", ""))
    {
      turningOff();
    }
    esp_restart();
  }

  bool res;
  // res = wm.autoConnect(); // auto generated AP name from chipid
  // res = wm.autoConnect("AutoConnectAP"); // anonymous ap
  res = wm.autoConnect("VioletMonitor", ""); // password protected ap

  if (!res)
  {
    Serial.println("Failed to connect or hit timeout");

    // ESP.restart();
  }
  else
  {
    // if you get here you have connected to the WiFi
    Serial.println("connected...yeey :)");
    // Serial.println(url);

    http.begin(url);
    int httpResponseCode = http.GET();
    if (httpResponseCode == 200)
    {
      // wm.disconnect();
      WiFi.mode(WIFI_OFF);
      Serial.print("HTTP ");
      Serial.println(httpResponseCode);
      String payload = http.getString();
      Serial.println();
      // Serial.println(payload);
      display.init(115200); // enable diagnostic output on Serial
      display.flush();

      DeserializationError error = deserializeJson(doc, payload);

      // Test if parsing succeeds
      if (error)
      {
        Serial.print(F("deserializeJson() failed: "));
        Serial.println(error.f_str());
        return;
      }

      int time = millis();
      int tmp = time;
      int lowPulse = 0;
      int pulse = 0;
      int bat_pin_cnt = 0;
      int prev_bat_pin_state = 0;
      int bat_pin_state = 0;
      int fronts_time = 0;
      int fronts_cnt = 0;
      chargeDone = chargerOn;

      while (((millis() - time) < 10000) && !levelDone)
      {
        int bat_pin = digitalRead(BAT_LEVEL_PIN);
        if (bat_pin && bat_pin_cnt < 100)
        {
          bat_pin_cnt++;
        }
        if (!bat_pin && bat_pin_cnt > 0)
        {
          bat_pin_cnt--;
        }
        if (bat_pin_cnt < 20)
        {
          bat_pin_state = 0;
          // Serial.print("********************** bat_pin_low = ");
          // Serial.println(millis());
        }
        if (bat_pin_cnt > 80)
        {
          bat_pin_state = 1;
          // Serial.print("********************** bat_pin_high = ");
          // Serial.println(millis());
        }
        if (prev_bat_pin_state == 1 && bat_pin_state == 0)
        {
          chargeDone = false;
          int t = millis();
          fronts_time = t - tmp;
          Serial.print("()()()()()()()()()() front_time = ");
          Serial.println(fronts_time);
          if (fronts_time > 1000)
          {
            if (levelReady)
            {
              levelDone = true;
              batLevel = fronts_cnt;
            }
            levelReady = true;
            fronts_cnt = 1;
          }
          if ((fronts_time > 150) && (fronts_time < 1000) && levelReady)
          {
            fronts_cnt++;
          }
          tmp = t;
        }
        if (prev_bat_pin_state == 0 && bat_pin_state == 1)
        {
          chargeDone = false;
        }
        prev_bat_pin_state = bat_pin_state;
        delay(1);
      }

      if (batLevel > 4)
        batLevel = 4;

      Serial.print("\n========= batLevel = ");
      Serial.println(batLevel);

      const char *timeString = strToChar(utf8rus(doc["timeString"].as<String>()));
      const char *aside = strToChar(utf8rus(doc["aside"].as<String>()));
      const char *line1 = strToChar(utf8rus(doc["line1"].as<String>()));
      const char *line2 = strToChar(utf8rus(doc["line2"].as<String>()));
      const char *status = doc["status"];
      Serial.print("timeString = ");
      Serial.println(timeString);
      Serial.print("asise = ");
      Serial.println(aside);
      Serial.print("line1 = ");
      Serial.println(line1);
      Serial.print("line2 = ");
      Serial.println(line2);
      Serial.print("status = ");
      Serial.println(status);

      if (!strcmp(status, "good"))
      {
        pixels.setPixelColor(0, pixels.Color(0, brightness.toInt(), 0));
      }
      else if (!strcmp(status, "bad"))
      {
        pixels.setPixelColor(0, pixels.Color(brightness.toInt(), 0, 0));
      }
      else if (!strcmp(status, "neutral"))
      {
        pixels.setPixelColor(0, pixels.Color(0, 0, brightness.toInt()));
      }
      pixels.show(); // Send the updated pixel colors to the hardware.

      drawAsideText(&display, aside, BIG_FONT);
      drawTimeText(&display, timeString, MIN_FONT, false);
      drawLine1(&display, line1, BIG_FONT, false);
      drawLine2(&display, line2, MIN_FONT, false);
      if (chargerOn)
      {
        if (chargeDone)
        {
          drawBat(&display, batLevelStr[4], &BatFont, false);
        }
        else
        {
          drawBat(&display, batLevelStr[5], &BatFont, false);
        }
      }
      else
      {
        drawBat(&display, batLevelStr[batLevel], &BatFont, false);
      }
      display.update();
      display.powerDown();
    }
    else
    {
      Serial.print("Error code: ");
      Serial.println(httpResponseCode);
      Serial.println(":-(");
      String text = "Ошибка " + String(httpResponseCode);
      pixels.clear();
      pixels.show();
      drawStatusText(&display, strToChar(utf8rus(text)), NORM_FONT);
      // turningOff();
    }
    http.end();
  }
  if (!chargerOn)
  {
    Serial.println(sleepTimeMs[update_time.toInt()] * 1000 - (millis() * 1000));
    esp_sleep_enable_timer_wakeup(sleepTimeMs[update_time.toInt()] * 1000 - (millis() * 1000));

    esp_deep_sleep_start();
  }
  else
  {
    delay(sleepTimeMs[update_time.toInt()] - millis());
    esp_restart();
  }
}

void loop()
{
}

String getParam(String name)
{
  // read parameter from server, for customhmtl input
  String value;
  if (wm.server->hasArg(name))
  {
    value = wm.server->arg(name);
  }
  return value;
}

void saveParamCallback()
{
  Serial.println("[CALLBACK] saveParamCallback fired");
  url = getParam("custom_url");
  update_time = getParam("update_time");
  brightness = getParam("brightness_input");
  Serial.println("PARAM custom_url = " + url);
  Serial.println("PARAM custom_radio = " + update_time);
  Serial.println("PARAM brightness = " + brightness);
  preferences.begin("preferences", false);
  preferences.putString("url", url);
  preferences.putString("update_time", update_time);
  preferences.putString("brightness", brightness);
  preferences.end();
}

void check_wakeup_reason()
{
  esp_sleep_wakeup_cause_t wakeup_reason;
  uint64_t wake_pin;
  wakeup_reason = esp_sleep_get_wakeup_cause();

  Serial.println("===========WAKE UP");
  switch (wakeup_reason)
  {
  case ESP_SLEEP_WAKEUP_TIMER:
    Serial.println("Wakeup caused by timer");
    break;
  case ESP_SLEEP_WAKEUP_EXT0:
    Serial.println("Wakeup caused by external signal using RTC_IO");
    // checkButton();
    break;

  case ESP_SLEEP_WAKEUP_EXT1:
    wake_pin = esp_sleep_get_ext1_wakeup_status();
    wake_pin = log(wake_pin) / log(2);
    Serial.print("GPIO ");
    Serial.println(wake_pin);
    Serial.println("Wakeup caused by external signal using RTC_CNTL");
    if (wake_pin == POWER_PIN)
    {
      turnOffFlag = !turnOffFlag;
      Serial.print("========== turnOffFlag = ");
      Serial.println(turnOffFlag);
      while (digitalRead(POWER_PIN))
      {
      }
    }
    if (wake_pin == OPTIONS_PIN)
    {
      optionsBtnPressed = !optionsBtnPressed;
      Serial.print("========== optionsBtnPressed = ");
      Serial.println(optionsBtnPressed);
      while (digitalRead(OPTIONS_PIN))
      {
      }
    }
    if (wake_pin == CHARGER_PIN)
    {
      chargerOn = true;
    }
    break;
  case ESP_SLEEP_WAKEUP_TOUCHPAD:
    Serial.println("Wakeup caused by touchpad");
    break;
  case ESP_SLEEP_WAKEUP_ULP:
    Serial.println("Wakeup caused by ULP program");
    break;
  default:
    Serial.printf("Wakeup was not caused by deep sleep: %d\n", wakeup_reason);
    break;
  }
}

String utf8rus(String source)
{
  int i, k;
  String target;
  unsigned char n;
  char m[2] = {'0', '\0'};
  k = source.length();
  i = 0;
  while (i < k)
  {
    n = source[i];
    i++;
    if (n >= 0xC0)
    {
      switch (n)
      {
      case 0xD0:
      {
        n = source[i];
        i++;
        if (n == 0x81)
        {
          n = 0xA8;
          break;
        }
        if (n >= 0x90 && n <= 0xBF)
          n = n + 0x30;
        break;
      }
      case 0xD1:
      {
        n = source[i];
        i++;
        if (n == 0x91)
        {
          n = 0xB8;
          break;
        }
        if (n >= 0x80 && n <= 0x8F)
          n = n + 0x70;
        break;
      }
      }
    }
    m[0] = n;
    target = target + String(m);
  }
  return target;
}

const char *strToChar(String str)
{
  const int length = str.length();
  char *char_array = new char[length + 1];

  // copying the contents of the
  // string to char array
  strcpy(char_array, str.c_str());
  const char *out = char_array;
  return out;
}
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

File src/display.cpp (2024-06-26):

// #include <GxEPD.h>
#include <GxDEPG0290BS/GxDEPG0290BS.h>
#include <display.h>

#define DISPLAY_PADDING 4
#define TEXT_PADDING 10
#define ASIDE_WIDTH 100

void drawAsideText(GxDEPG0290BS *display, const char *string, const GFXfont *font)
{
    display->setRotation(3);
    display->setFont(font);
    display->setTextColor(GxEPD_WHITE);
    int16_t tbx, tby;
    uint16_t tbw, tbh;
    display->getTextBounds(string, 0, 0, &tbx, &tby, &tbw, &tbh);
    uint16_t x = ((ASIDE_WIDTH - tbw) / 2) - tbx;
    uint16_t y = ((display->height() - tbh) / 2) - tby;
    display->fillRect(0, 0, ASIDE_WIDTH, display->height(), GxEPD_BLACK);
    display->setCursor(x, y);
    display->print(string);
}

void drawLine2(GxDEPG0290BS *display, const char *string, const GFXfont *font, bool partial = false)
{
    display->setRotation(3);
    display->setFont(font);
    display->setTextColor(GxEPD_BLACK);
    int16_t tbx, tby;
    uint16_t tbw, tbh;
    display->getTextBounds(string, 0, 0, &tbx, &tby, &tbw, &tbh);
    // uint16_t x = display->width() - tbw - DISPLAY_PADDING;
    uint16_t x = ASIDE_WIDTH + TEXT_PADDING;
    uint16_t y = tbh + TEXT_PADDING;
    display->setCursor(x, y);
    display->print(string);
}
void drawLine1(GxDEPG0290BS *display, const char *string, const GFXfont *font, bool partial = false)
{
    display->setRotation(3);
    display->setFont(font);
    display->setTextColor(GxEPD_BLACK);
    int16_t tbx, tby;
    uint16_t tbw, tbh;
    display->getTextBounds(string, 0, 0, &tbx, &tby, &tbw, &tbh);
    uint16_t x = ASIDE_WIDTH + TEXT_PADDING;
    uint16_t y = ((display->height() - tbh) / 2) - tby;
    display->setCursor(x, y);
    display->print(string);
}
void drawTimeText(GxDEPG0290BS *display, const char *string, const GFXfont *font, bool partial = false)
{
    display->setRotation(3);
    display->setFont(font);
    display->setTextColor(GxEPD_BLACK);
    int16_t tbx, tby;
    uint16_t tbw, tbh;
    display->getTextBounds(string, 0, 0, &tbx, &tby, &tbw, &tbh);
    uint16_t x = ASIDE_WIDTH + TEXT_PADDING;
    uint16_t y = display->height() - TEXT_PADDING;
    // Serial.print("=============== display height = ");
    // Serial.println(display->height());
    // Serial.print("=============== y = ");
    // Serial.println(y);
    // Serial.print("=============== tby = ");
    // Serial.println(tby);
    // Serial.print("=============== tbh = ");
    // Serial.println(tbh);
    display->setCursor(x, y);
    display->print(string);
}

void drawTurnOff(GxDEPG0290BS *display, const char *string, const GFXfont *font)
{
    display->init(115200);
    display->setRotation(3);
    display->setFont(font);
    display->setTextColor(GxEPD_BLACK);
    int16_t tbx, tby;
    uint16_t tbw, tbh;
    display->getTextBounds(string, 0, 0, &tbx, &tby, &tbw, &tbh);
    uint16_t x = ((display->width() - tbw) / 2) - tbx;
    uint16_t y = ((display->height() - tbh) / 2) - tby;
    display->setCursor(x, y);
    display->print(string);
    display->update();
    display->powerDown();
}

void drawBat(GxDEPG0290BS *display, const char *string, const GFXfont *font, bool partial = false)
{
    display->setRotation(3);
    display->setFont(font);
    display->setTextColor(GxEPD_BLACK);
    int16_t tbx, tby;
    uint16_t tbw, tbh;
    display->getTextBounds(string, 0, 0, &tbx, &tby, &tbw, &tbh);
    uint16_t x = display->width() - tbw;
    // uint16_t x = display->width() - tbw - DISPLAY_PADDING;
    // uint16_t x = ASIDE_WIDTH + DISPLAY_PADDING;
    // uint16_t y = tbh + DISPLAY_PADDING;
    uint16_t y = tbh;
    display->setCursor(x, y);
    display->print(string);
    if (partial)
    {
        display->updateWindow(x, y - tbh, tbw, tbh, true);
    }
    // display->powerDown();
    // Serial.println(x);
    // Serial.println(y);
    // Serial.println(tbw);
    // Serial.println(tbh);
}

void drawStatusText(GxDEPG0290BS *display, const char *string, const GFXfont *font)
{
    display->init(115200);
    display->setRotation(3);
    display->setFont(font);
    display->setTextColor(GxEPD_BLACK);
    int16_t tbx, tby;
    uint16_t tbw, tbh;
    display->getTextBounds(string, 0, 0, &tbx, &tby, &tbw, &tbh);
    uint16_t x = ((display->width() - tbw) / 2) - tbx;
    uint16_t y = ((display->height() - tbh) / 2) - tby;
    display->setCursor(x, y);
    display->print(string);
    display->update();
    display->powerDown();
}

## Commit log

2024-05-14 power off on btn
2024-05-17 3d models
    [B82472G6472M000.STEP, ESP32-WROOM-32--3DModel-STEP-1.STEP]
2024-05-21 charger in work
2024-05-21 add led component
    [SK6805-2427.stp]
2024-05-22 schematic in work
2024-05-23 pcb in work
2024-05-27 add shutter filters
2024-05-28 pcb + gerber
    [main_BOM.csv]
2024-06-10 fix pcb
    [1 - Top.gbr, 2 - Bottom.gbr, BoardOutline.gbr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]
2024-06-11 battery plug add
2024-06-12 charger pin transistor
2024-06-17 BOM x5
    [BOM for 5 boards.xlsx, main_BOM.csv]
2024-06-18 led board
    [led_board.step]
2024-06-26 bat level
    [Расчет времени работы.xlsx]
2024-06-27 draw bat level fix
    [main.cpp]
2024-07-01 E ink driver scheme
2025-02-13 move files
    [Assembly v8.step, Assembly v9.step, BC817-16,235.step.SLDPRT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]
